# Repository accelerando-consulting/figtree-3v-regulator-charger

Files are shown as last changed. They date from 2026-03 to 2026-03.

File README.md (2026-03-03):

# Figtree - a simple battery maintenance board

This board takes in 4-6v from USB, solar panel or other DC, and charges a lithium battery.

It also delivers regulated 3.3v at up to 600mA.

Basically it is an all in one "Run a microcontroller board off solar and/or battery" hack.

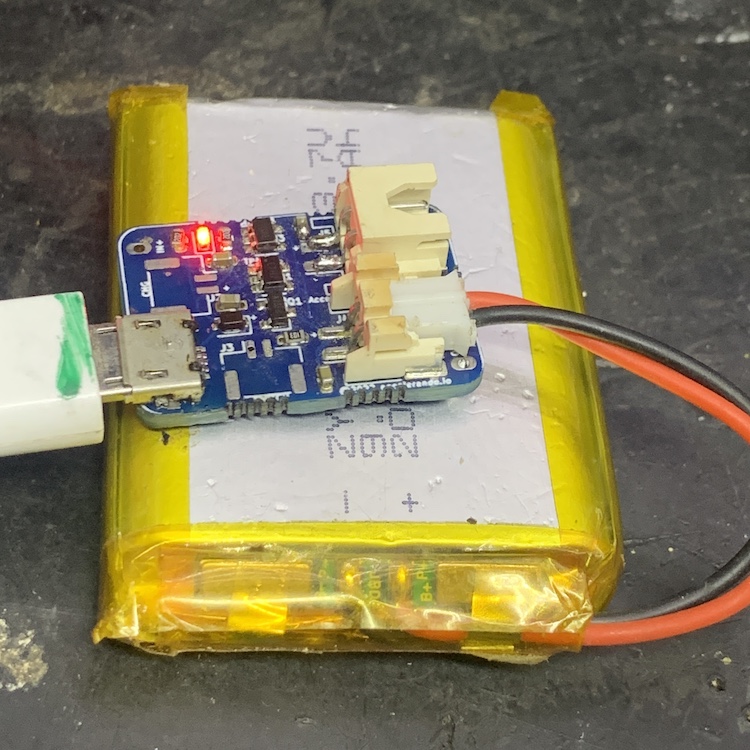
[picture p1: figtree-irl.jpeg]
Photograph of board in use


The board has three key connections

  * Charging power in
  * Battery in/out
  * Project power out

There are solder pads for wires, and JST connector footprints for each of these.   You can use one
or the other.  

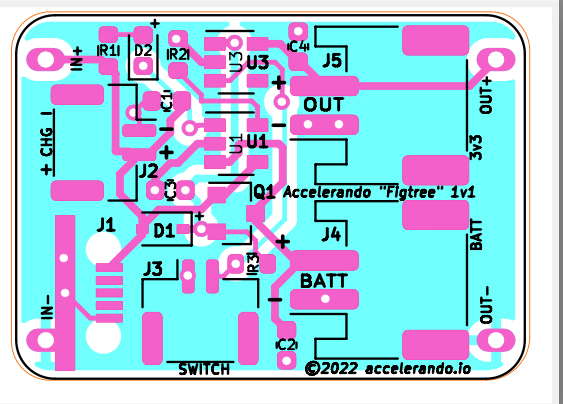
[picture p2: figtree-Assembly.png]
Assembly diagram


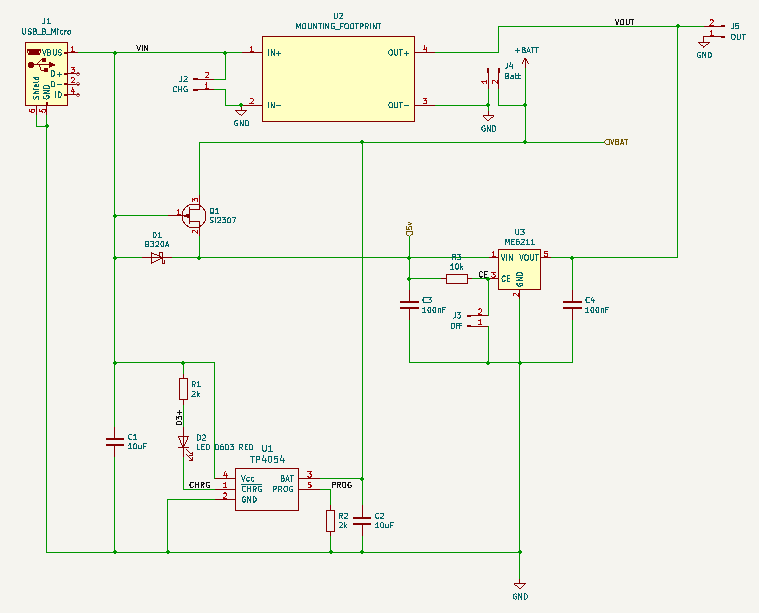
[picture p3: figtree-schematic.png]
Circuit diagram


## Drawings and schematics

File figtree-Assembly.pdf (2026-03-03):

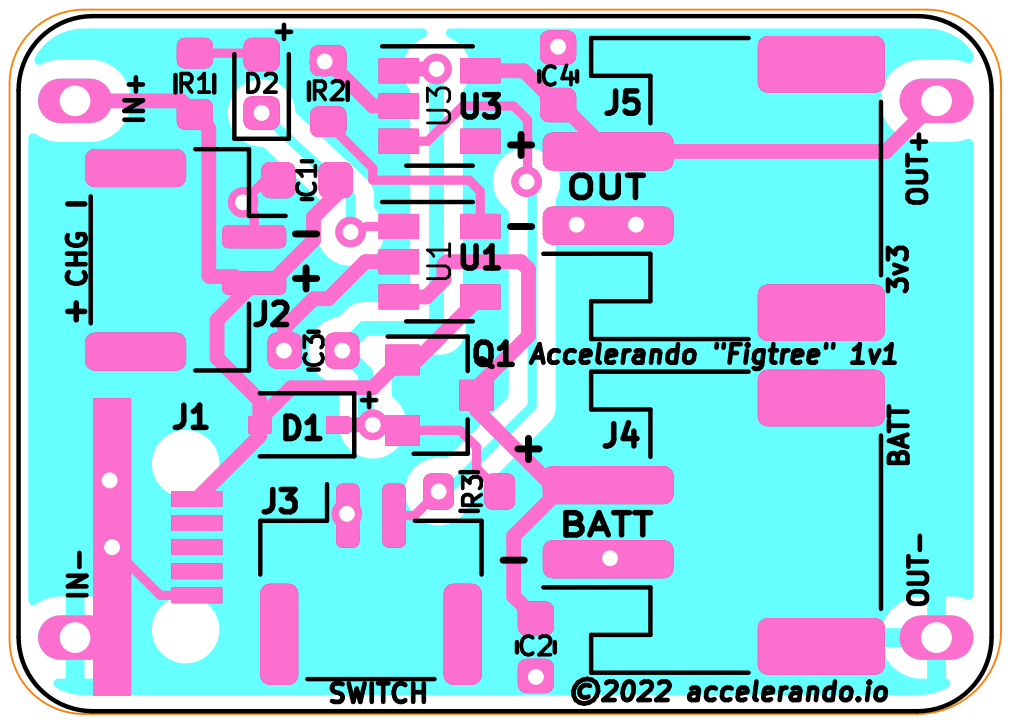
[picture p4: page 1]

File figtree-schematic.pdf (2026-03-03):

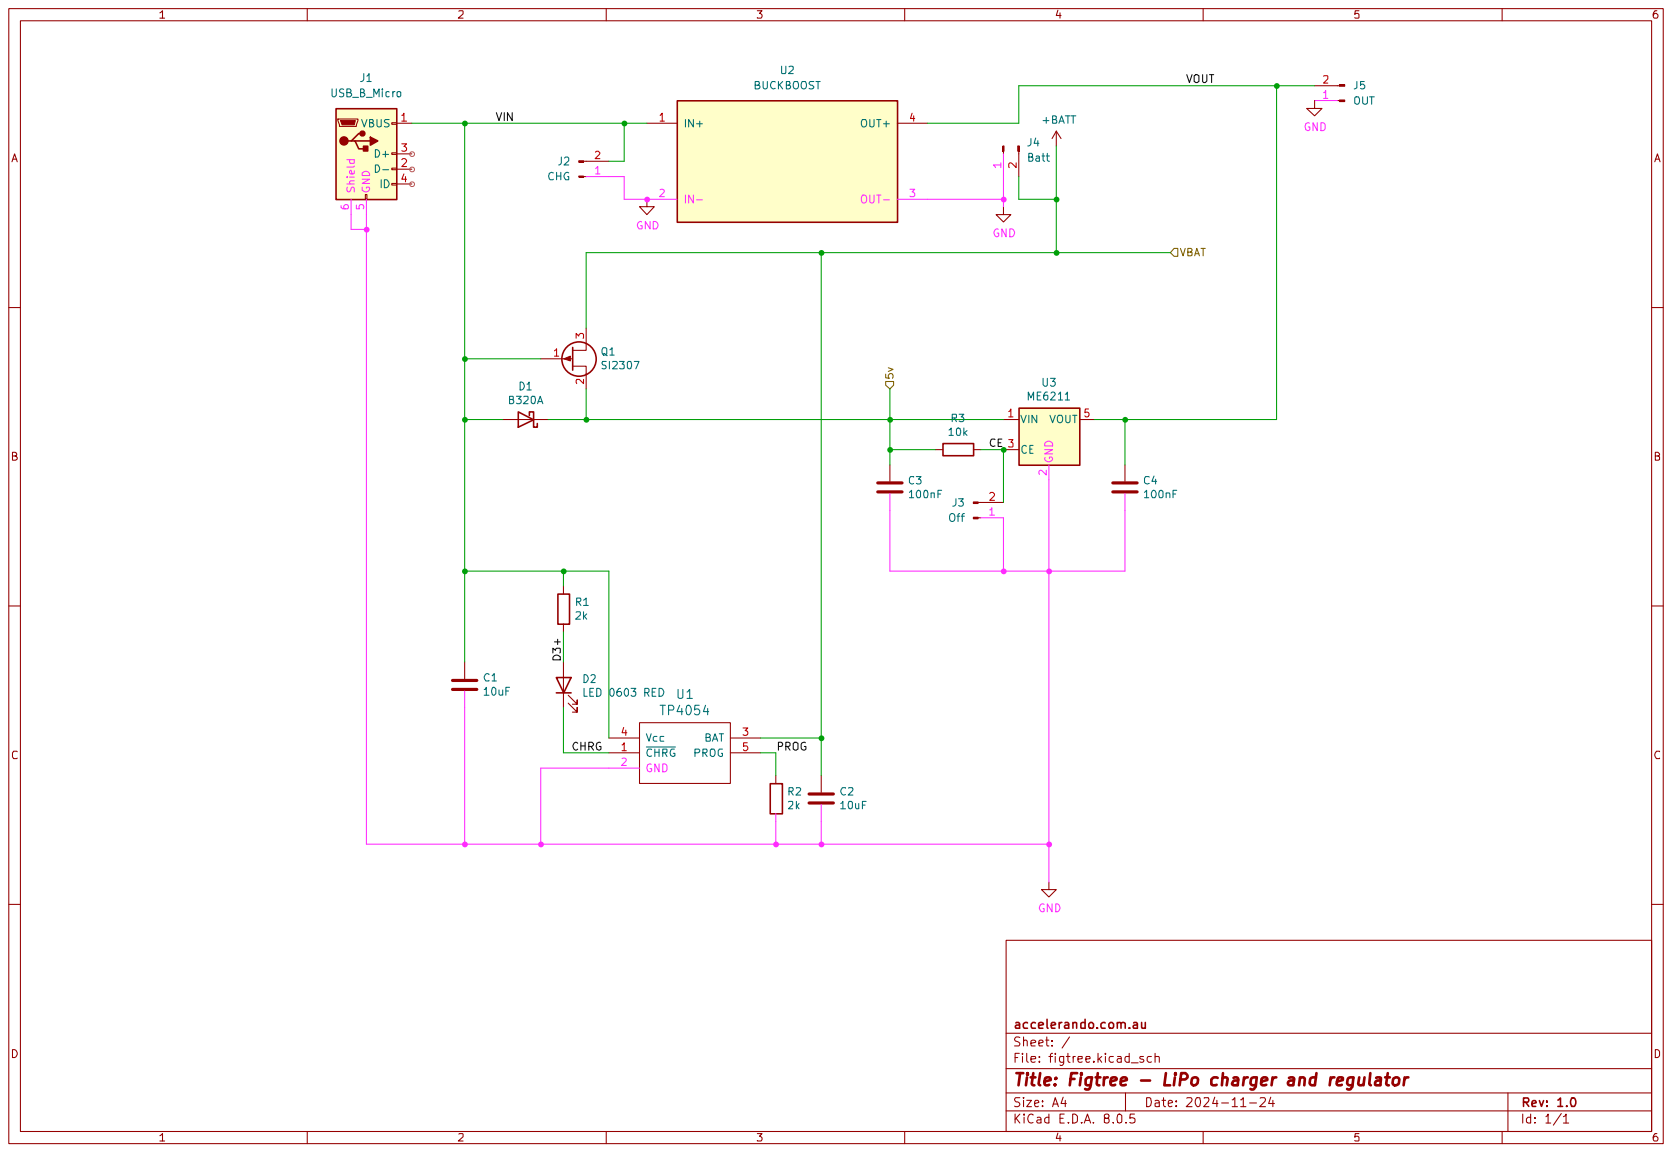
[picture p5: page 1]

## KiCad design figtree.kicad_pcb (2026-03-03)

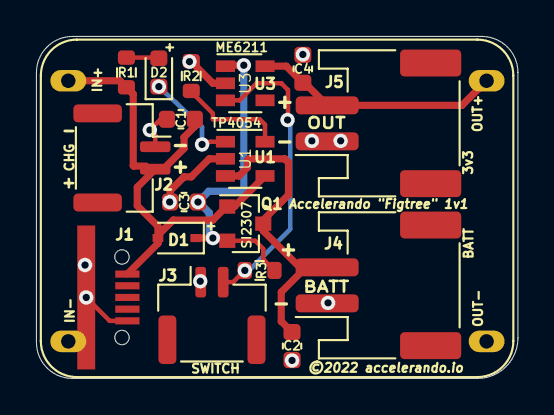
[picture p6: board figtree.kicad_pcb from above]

Board: 2 copper layers, 26.8 x 19.0 mm, 18 parts (0 on the bottom side), 9 nets.

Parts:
C1, C2: 10uF; C_0603_1608Metric
C3, C4: 100nF; C_0603_1608Metric
D1: B320A; D_SOD-323
D2: LED 0603 RED; LED_0603_1608Metric
J1: USB_B_Micro; USB_Micro_SMD
J2: CHG; JST_GH_SM02B-GHS-TB_1x02-1MP_P1.25mm_Horizontal
J3: Off; JST_GH_SM02B-GHS-TB_1x02-1MP_P1.25mm_Horizontal
J4: Batt; JST_PH_S2B-PH-SM4-TB_1x02-1MP_P2.00mm_Horizontal
J5: OUT; JST_PH_S2B-PH-SM4-TB_1x02-1MP_P2.00mm_Horizontal
Q1: SI2307; SOT-23
R1, R2: 2k; R_0603_1608Metric
R3: 10k; R_0603_1608Metric
U1: TP4054; SOT-23-5
U2: BUCKBOOST
U3: ME6211; SOT-23-5

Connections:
+BATT: C2.1, J4.2, Q1.3 (D), U1.3 (BAT)
/5v: C3.1, D1.1 (K), Q1.2 (S), R3.2, U3.1 (VIN)
/CE: J3.2, R3.1, U3.3 (CE)
/CHRG: D2.1 (K), U1.1 (~CHRG)
/D3+: D2.2 (A), R1.2
/PROG: R2.1, U1.5 (PROG)
/VIN: C1.1, D1.2 (A), J1.1 (VBUS), J2.2, Q1.1 (G), R1.1, U1.4 (Vcc), U2.1 (IN+)
/VOUT: C4.1, J5.2, U2.4 (OUT+), U3.5 (VOUT)
GND: C1.2, C2.2, C3.2, C4.2, J1.5 (GND), J1.6 (Shield), J2.1, J3.1, J4.1, J5.1, R2.2, U1.2 (GND), U2.2 (IN-), U2.3 (OUT-), U3.2 (GND)

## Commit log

2022-04-12 Buckbatt module, millable power supply
    [buckbatt.kicad_pcb, buckbatt.sch]
2026-03-03 Rename to figtree
    [figtree.kicad_pcb, figtree.kicad_sch]
2026-03-03 Add panelised board
    [panel.kicad_pcb]
2026-03-03 Update PCB for rename
    [figtree.kicad_pcb, figtree.kicad_sch]
2026-03-03 Update png and pdfs
    [figtree.kicad_sch]
2026-03-03 Add photograph of board in use

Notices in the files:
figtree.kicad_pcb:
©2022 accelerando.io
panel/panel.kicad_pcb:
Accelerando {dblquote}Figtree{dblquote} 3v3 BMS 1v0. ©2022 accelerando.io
